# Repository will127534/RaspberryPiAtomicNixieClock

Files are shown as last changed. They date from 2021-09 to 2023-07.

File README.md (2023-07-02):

# RaspberryPi Atomic Nixie Clock

[Full description is in here](https://www.willwhang.dev/RaspberryPi-Atomic-Nixie-Clock/)



## Sys Arch


## Source File List
* PCB - PCB related board designed with KiCad v5.99 nightly
* FPGA Code - Verilog files
* Raspberry Pi Code - Python + C code to interact with FPGA

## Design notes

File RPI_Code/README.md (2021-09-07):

# Raspberry Pi Code

The code is intended to document the communication with the FPGA and SA.3xm Atomic Clock.

## Setup

### Python Library
```
pip install -r requirements.txt
```
Library List:
* influxdb Client
* pyserial
* simple_pid
* adafruit-circuitpython-TMP117
* python-dateutil

### GPS
gpsd is not actually needed but I'm using it to parse some GPS NEMA data and connect to ntpd, so the program is designed around gpsd and take its serial dump and parse the UBX format phase error data.

Note also you should enable UBX-TIM-TP output of the uBlox GPS module.

### InfluxDB
InfluxDB is used to collect time series data. The setting is in **dbSetting.py**

## Code List

* **uploadClock.py**
    * The main program to communicate with FPGA
    * Reading FPGA data, including TDC7200 measurement
    * Setting up FPGA time and inital PPS alignment
    * Reading GPS Serial data from stdin and calculate corrected PPS error
    * Nixie Tube animate to prevent cathode poisoning
* **uploadMAC.py**
    * Reading MAC status and creating UDP server for other program to communicate with MAC. (**calibrateClock.py**)
* **calibrateClock.py**
    * The program to read current PPS error using InfluxDB and tune the clock EFC. The EFC tuning cmd is send via UDP package to **uploadMAC.py**. The tuning algroithm is a simple accumlated error.
* **readADC**
    * The C program to poll ADC reading and output frequency and Vrms data to stdio.
    * `gcc -o readADC ./readADC.c -lm -mcpu='cortex-a72' -O3`
    * `./readADC [folderPath]`
* **autoBrightness**
    * The C program to control Nixie Tube brightness. Reading Lux sensor and send cmd to FPGA.
    * `g++ -o autoBrightness ./main.cpp ./Adafruit_PWMServoDriver.cpp ./TSL2561.cpp -lwiringPi`
    * `autoBrightness [lowest_pwm]`
* **fanControl.py**
    * Reading TMP117 and using PID loop on the bottom fan to maintain the clock temperature
* mountdrive.sh
    * Creating a 512MB ramdisk to store AC waveform, and mounting NVMe drive.
* **moveFile.py**
    * Copy the file from ramdisk to NVMe drive.
* **uploadFPGA.py**
    * Uploading FPGA bin file via SPI
* **uploadFPGA.sh**
    * The helper shell script of **uploadFPGA.py**
* **dbSetting.py**
    * The settings for InfluxDB location

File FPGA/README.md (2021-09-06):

# Verilog Files

Designed for iCE5LP

## File List
 * **main.v** - top verilog code
 * Driver
     * **ADS8681.v** - ADS8681 Driver
     * **tdc7200.v** - TDC7200 Driver
     * **nixie.v** - HV5623/HV5623 Driver
     * **spi_master.v** - SoftIP SPI, used by the Drivers
     * **spi_slave.v** - Using HardIP block
 * Utility
     * **coarsecounter.v** - Simple Counter
     * **bin2bcd.v** - Binary to BCD Code for Nixie Tube
     * **delayPPS.v** - Generate constant cycle delay for a given input signal
     * **fifo.v** - FIFO using BRAM blocks
     * **pps.v** - Generate PPS signal, and optionaly can align with external PPS
     * **pwm.v** - Actually it is generating PDM signal
     * **rtc.v** - A really simple RTC, just counting the time for Nixie Clock
 * Testbench
     * **counter_test.v** - coarsecounter.v testing
     * **pdm_test.v** - pwm.v testing
     * **spi_m_test.v**
     * **spi_s_test.v**
 * **pins.pcf** - pin definition

## iCECube2 output 
> Device Utilization Summary
    LogicCells                  :	2050/3520
    PLBs                        :	346/440
    BRAMs                       :	16/20
    IOs and GBIOs               :	31/35
    PLLs                        :	0/1
    I2Cs                        :	0/2
    SPIs                        :	2/2
    DSPs                        :	0/4
    SBIOODs                     :	3/4
    LEDDRVs                     :	0/1
    RGBDRVs                     :	0/1
    IRDRVs                      :	0/1
    LEDDIPs                     :	0/1
    LFOSCs                      :	0/1
    HFOSCs                      :	1/1

>Number of clocks: 5
Clock: main|CLOCK | Frequency: 65.57 MHz | Target: 15.00 MHz
Clock: main|SCK | Frequency: 394.30 MHz | Target: 15.00 MHz
Clock: osc2.hfosc/CLKHF | Frequency: 113.89 MHz | Target: 48.00 MHz
Clock: rpi_adc_dev.sb_spi_inst/SCKO | Frequency: N/A | Target: 25.00 MHz
Clock: rpi_spi_dev.sb_spi_inst/SCKO | Frequency: N/A | Target: 25.00 MHz

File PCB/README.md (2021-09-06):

# PCB Files
Designed with KiCad v5.99 nightly build

## PCB Errata
1. EMC2301 package is wrong
2. eFUSE (TPS259270) Enable pin should connect to VIN via a resistor 

## Images



good luck finding the stock for LDO and DC-DC converters :D

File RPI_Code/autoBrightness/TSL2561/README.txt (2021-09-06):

**DEPRECATED**
Please use new version of library:
https://github.com/adafruit/Adafruit_TSL2561

---------------------------
This is an Arduino library for the TSL2561 digital luminosity (light) sensors. 

Pick one up at http://www.adafruit.com/products/439

To download. click the DOWNLOADS button in the top right corner, rename the uncompressed folder TSL2561. Check that the TSL2561 folder contains TSL2561.cpp and TSL2561.h

Place the TSL2561 library folder your <arduinosketchfolder>/libraries/ folder. You may need to create the libraries subfolder if its your first library. Restart the IDE.

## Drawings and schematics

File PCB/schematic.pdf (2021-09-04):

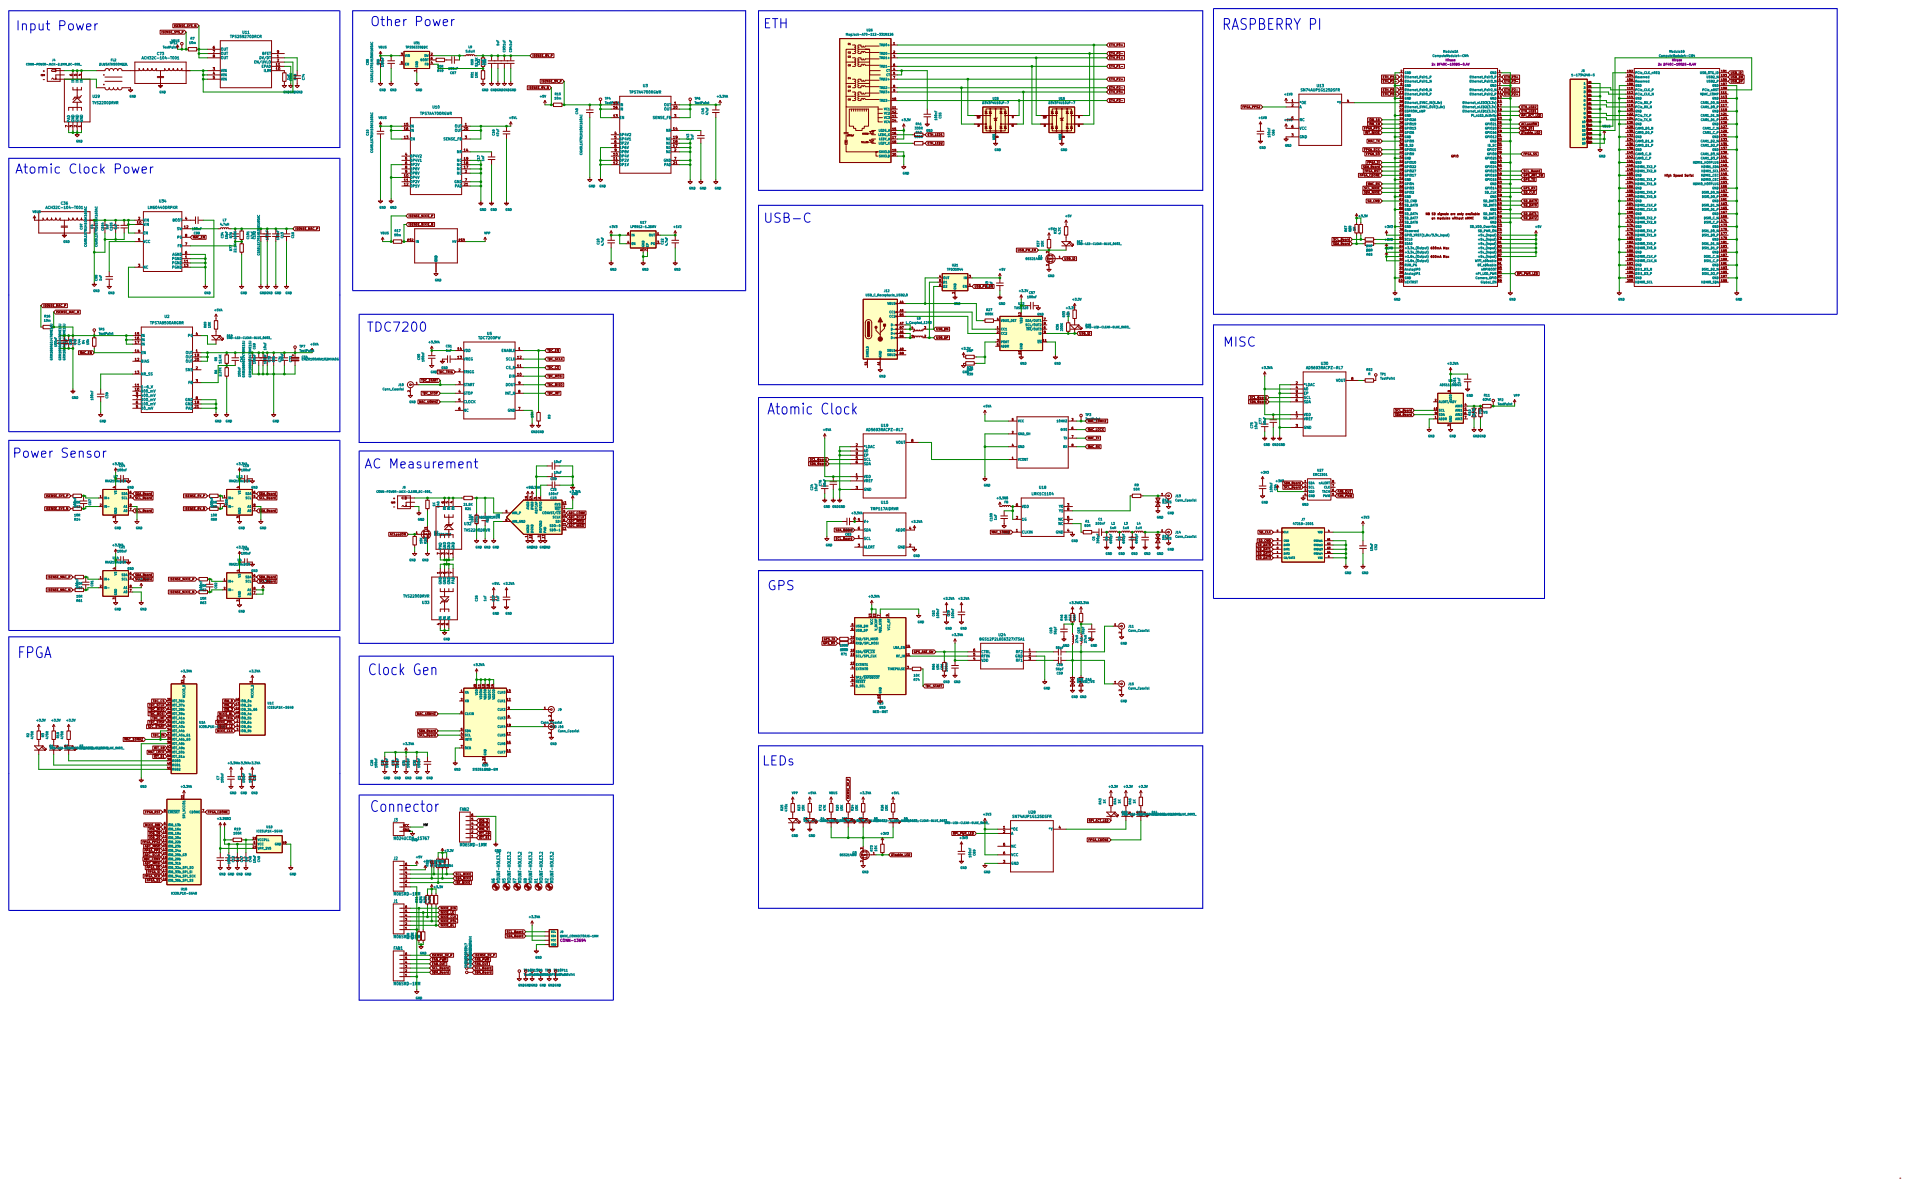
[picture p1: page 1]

1 SW 2 VIN 3 FB 4 EN 5 BOOT 6 U31 TPS56339DDC

D14SMD-LED-CLEAR-BLUE_0603_ D10SMD-LED-CLEAR-BLUE_0603_ GND

600mA Max 600mA Max NB SD signals are only available

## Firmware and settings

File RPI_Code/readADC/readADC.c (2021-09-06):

#define _GNU_SOURCE
#include <stdint.h>
#include <unistd.h>
#include <stdio.h>
#include <stdlib.h>
#include <getopt.h>
#include <fcntl.h>
#include <sys/ioctl.h>
#include <linux/types.h>
#include <linux/spi/spidev.h>
#include <string.h>
#include <stdbool.h>
#include <time.h>
#include <fcntl.h>
#include <sys/time.h>
#include <inttypes.h>
#include <math.h>
#include <sched.h>
#include <sys/mman.h>
#include <sys/types.h>
#include <sys/wait.h>
#include <sys/types.h>
#include <sys/ipc.h>
#include <sys/shm.h>

// File Related Var
char *folder;
FILE *ADCFile;
FILE *FreqFile;
bool changed_FreqFile,changed_ADCFile;

// Calculate Freq, Vrms, Max, Low Voltage Related Var
bool positive_flag = 0;
uint16_t last_timestamp = 0;
double last_timestamp_fp = 0;
double last_adc_voltage = 0;
double heighest_voltage = 0;
double lowset_voltage = 0;
double rms_voltage_square_sum = 0;
int rms_voltage_count = 0;

// FPGA data Related Var
uint16_t *read_count;
uint32_t *secondsOfDay;
uint16_t *pps_timestamp;
char *buf_data;

//FIFO Related Var
volatile uint16_t *queue_write;
volatile uint16_t *queue_read;
const uint16_t queue_length = 3000;

//Read FIFO FPGA CMD
const char buf_readFIFO[9] = {128+2,0x00,0x00,0x00,0x00,0x00,0x00,0x00,0x00};

//Init SPIdev
int spi_init(char filename[40]){
    int file;

    if ((file = open(filename,O_RDWR)) < 0)
    {
        printf("Failed to open the bus.");
        /* ERROR HANDLING; you can check errno to see what went wrong */
        exit(1);
    }
    return file;
}

//Clear FPGA FIFO
void setup_fifo(int file, struct spi_ioc_transfer xfer_conf){
    int status;
    char buf[2] = {0x00,0x04};
    //xfer.tx_buf = (unsigned long) buf_out;
    //xfer.len = 4; /* Length of  command to write*/
    xfer_conf.rx_buf = (unsigned long) NULL;
    xfer_conf.tx_buf = (unsigned long) buf;
    xfer_conf.len = 2; /* Length of Data to read */

    status = ioctl(file, SPI_IOC_MESSAGE(1), &xfer_conf);
    if (status < 0) {
        perror("SPI_IOC_MESSAGE");
        return ;
    }
}

//Write Frequency to File
void writeFrequency(uint16_t timestamp, double frequency, double rms_voltage){
    time_t current_time;
    struct tm * time_info;
    char buffer[200] = {0};

    time_t s;  // Seconds
    struct timespec spec;
    clock_gettime(CLOCK_REALTIME, &spec);
    s  = spec.tv_sec;
    sprintf(buffer, "%"PRIdMAX".%09ld,%d,%f,%f\n",(intmax_t)s, spec.tv_nsec,timestamp,frequency,rms_voltage);

    fwrite(buffer,1,strlen(buffer),FreqFile);
    time(&current_time);
    time_info = localtime(&current_time);
    if ((time_info->tm_min % 5 == 0) & (changed_FreqFile == 0)) //Switch file per 5 min
    {
        char timeString[100] = {0};
        char fileString[100] = {0};
        strftime(timeString, sizeof(timeString), "ACFREQ_%Y%m%d_%H%M%S.txt", time_info);
        sprintf(fileString,"%s%s",folder,timeString);

        fclose(FreqFile);
        FreqFile = fopen(fileString,"w" );
        changed_FreqFile = 1;
    }
    if ((time_info->tm_min % 5 == 1) & (changed_FreqFile == 1))
    {
        changed_FreqFile = 0;
    }
}

//Process ADC raw data from FPGA
void process_data(int length, uint8_t* buf_in){
    for (int k=0;k<length;k++){
        for (int i=0;i<4;i++){
                uint16_t timestamp = (uint16_t)buf_in[1+k*16+i*4]*256+(uint16_t)buf_in[0+k*16+i*4];
                uint16_t adc_data = (uint16_t)buf_in[3+k*16+i*4]*256+(uint16_t)buf_in[2+k*16+i*4];
                int fifo = 0;
                if(k==0 & i == 0)
                    fifo = *read_count;
                double voltage = ((double)adc_data - 32813.7864224796) * 0.001032546059765 -0.013938492775101;
                if(voltage > heighest_voltage) heighest_voltage = voltage;
                if(voltage < lowset_voltage) lowset_voltage = voltage;
                char buffer[200] = {0};
                //ASCII Format
                //sprintf(buffer, "%d,%d,%d,%d,%f\n",*secondsOfDay,fifo,timestamp,adc_data,voltage);
                //printf("%s",buffer);
                //fwrite(buffer,1,strlen(buffer),ADCFile);

                //Binary File Format 
                memcpy(buffer,secondsOfDay,sizeof(uint32_t));
                memcpy(buffer+4,read_count,sizeof(uint32_t));
                memcpy(buffer+8,&timestamp,sizeof(uint16_t));
                memcpy(buffer+10,&adc_data,sizeof(uint16_t));
                fwrite(buffer,1,12,ADCFile);

                if ( voltage>0 && positive_flag == 0 ){ //Zero corssing from negitive to positive
                    double current_timestamp_fp = -1 * last_adc_voltage / (voltage - last_adc_voltage);
                    uint16_t timestamp_duration = 0;
                    if(timestamp<last_timestamp) timestamp_duration = 50000-last_timestamp+timestamp;
                    else timestamp_duration = timestamp - last_timestamp;
                    double cycle_time = (double)timestamp_duration * 1 / 50000 + (current_timestamp_fp - last_timestamp_fp)* 1 / 50000;
                    double frequency = 1/cycle_time;
                    double rms_voltage = sqrt(rms_voltage_square_sum/rms_voltage_count);
                    printf("%f,%f,%5d.%0.5f,%5d.%0.5f,%f,%f,%f,%f,%f\n",last_adc_voltage,voltage,timestamp,current_timestamp_fp,last_timestamp,last_timestamp_fp,cycle_time,frequency,rms_voltage,heighest_voltage,lowset_voltage);
                    writeFrequency(timestamp,frequency,rms_voltage);
                    last_timestamp = timestamp;
                    last_timestamp_fp = current_timestamp_fp;
                    lowset_voltage = 0;
                    heighest_voltage = 0;
                    rms_voltage_square_sum = 0;
                    rms_voltage_count = 0;
                }

                rms_voltage_square_sum += voltage*voltage;
                rms_voltage_count += 1;

                positive_flag = (voltage>0);
                last_adc_voltage = voltage;
        }
    }
}


void main(int argc, char *argv[]){
    folder = argv[1];

    // Share Memory for Thread communication 
    int shm_id;
    shm_id = shmget(IPC_PRIVATE, 12+3000*16, IPC_CREAT | 0666);
    if (shm_id < 0) {
         printf("shmget error\n");
         exit(1);
    }

    // Forking two thread - Reading and Processing
    pid_t child_a, child_b;
    child_a = fork();

    if (child_a == 0) {
        /* Child code */
        printf("Read Thread Start\n");

        //Get the share memory
        char *shm_addr;
        shm_addr = shmat(shm_id, NULL, 0);
        if (shm_addr == (char *)(-1)) {
            perror("shmat");
            exit(1);
        }

        //Start of the SHM is the pointer of FIFO and FPGA data
        queue_write = (uint16_t*)shm_addr;
        queue_read = (uint16_t*)shm_addr + 2;

        read_count = (uint16_t*)shm_addr + 4;
        secondsOfDay = (uint32_t*)shm_addr + 6;
        pps_timestamp = (uint16_t*)shm_addr + 10;

        //FIFO Data is after this
        buf_data = (char*)shm_addr + 64;

        //Set write point to 0
        *queue_write = 0;

        //Lock the reading thread to CPU 2 only
        cpu_set_t  mask;
        CPU_ZERO(&mask);
        CPU_SET(2, &mask);
        int result = sched_setaffinity(0, sizeof(mask), &mask);


        //INIT SPI
        char buf_in_DATA[255*16+2];
        char buf_in_FIFO[9] = {0};
        int file=spi_init("/dev/spidev0.1");
        int file_conf=spi_init("/dev/spidev0.0"); 

        int mode = SPI_MODE_0;
        ioctl(file,SPI_IOC_WR_MODE,&mode);

        struct spi_ioc_transfer xfer[2];
        struct spi_ioc_transfer xfer_conf;
        memset((void*)&xfer_conf,0,sizeof(xfer_conf));
        memset((void*)xfer,0,sizeof(xfer));

        xfer[0].len = 4; 
        xfer[0].cs_change = 0; 
        xfer[0].delay_usecs = 0,
        xfer[0].speed_hz = 12500000, 
        xfer[0].bits_per_word = 8, 

        xfer[1].len = 4; 
        xfer[1].cs_change = 0; 
        xfer[1].delay_usecs = 0, 
        xfer[1].speed_hz = 12500000,
        xfer[1].bits_per_word = 8, 

        xfer_conf.len = 4; 
        xfer_conf.cs_change = 0; 
        xfer_conf.delay_usecs = 0, 
        xfer_conf.speed_hz = 6250000, 
        xfer_conf.bits_per_word = 8, 

        //CLEAR FIFO
        setup_fifo(file_conf,xfer_conf);

        while(1){
            //Read FIFO count, ADC_Tag, Current Time
            xfer_conf.rx_buf = (unsigned long) buf_in_FIFO;
            xfer_conf.tx_buf = (unsigned long) buf_readFIFO;
            xfer_conf.len = 9;

            int status = ioctl(file_conf, SPI_IOC_MESSAGE(1), &xfer_conf);
            if (status < 0)
                {
                perror("SPI_IOC_MESSAGE");
                return;
                }
            //printf("env: %02x %02x %02x %02x %02x\n", buf_out[0], buf_out[1], buf_out[2], buf_out[3],buf_out[4]);
            //printf("ret: %02x %02x %02x %02x %02x %02x %02x %02x %02x\n", buf_in_2[0], buf_in_2[1], buf_in_2[2], buf_in_2[3], buf_in_2[4], buf_in_2[5], buf_in_2[6], buf_in_2[7], buf_in_2[8]);

            *read_count = buf_in_FIFO[3]*256+buf_in_FIFO[2];
            *secondsOfDay = (int)buf_in_FIFO[8]*3600+(int)buf_in_FIFO[7]*60+(int)buf_in_FIFO[6];
            *pps_timestamp = buf_in_FIFO[5]*256+buf_in_FIFO[4];

            //printf("Reading....%d,%d,%d\n",*read_count,*pps_timestamp,*secondsOfDay);

            //If FIFO count is not zero then read the indicated amount
            if (*read_count == 0) continue;
            int transferCount = *read_count > 255 ? 255 : *read_count;

            xfer[0].rx_buf = (unsigned long) buf_in_DATA;
            xfer[0].tx_buf = (unsigned long) NULL;
            xfer[0].len = transferCount*16 + 2; 

            //printf("Reading....%d\n",transferCount);
            status = ioctl(file, SPI_IOC_MESSAGE(1), &xfer);
            if (status < 0){
                perror("SPI_IOC_MESSAGE");
                return;
            }

            //Put to SHM and advance write pointer
            memcpy(buf_data+*queue_write*16,buf_in_DATA+2,transferCount*16);
            int queue_write_next = (*queue_write+transferCount)%queue_length;
            //*queue_write += transferCount;
            *queue_write = queue_write_next;

            //Clear SPI buffer
            memset(buf_in_DATA,0,sizeof(buf_in_DATA));
        }
    } 
    else {
        printf("Process Thread Start\n");

        //Open file with timestamp
        time_t current_time;
        struct tm * time_info;
        time(&current_time);
        time_info = localtime(&current_time);

        char timeString[100] = {0};
        strftime(timeString, sizeof(timeString), "Waveform_%Y%m%d_%H%M%S.bin", time_info);
        char fileString[100] = {0};
        sprintf(fileString,"%s%s",folder,timeString);
        printf("Write to: %s\n",fileString);
        ADCFile = fopen( fileString,"w");
        //fcntl(ADCFile, F_SETFL, O_NONBLOCK);

        strftime(timeString, sizeof(timeString), "ACFREQ_%Y%m%d_%H%M%S.txt", time_info);
        sprintf(fileString,"%s%s",folder,timeString);
        printf("Write to: %s\n",fileString);
        FreqFile = fopen(fileString,"w");

        int current_fileSecond = 0;

        //Open SHM
        char *shm_addr;
        shm_addr = shmat(shm_id, NULL, 0);
        if (shm_addr == (char *)(-1)) {
            perror("shmat");
            exit(1);
        }

        queue_write = (uint16_t*)shm_addr;
        queue_read = (uint16_t*)shm_addr + 2;

        read_count = (uint16_t*)shm_addr + 4;
        secondsOfDay = (uint32_t*)shm_addr + 6;
        pps_timestamp = (uint16_t*)shm_addr + 10;

        buf_data = shm_addr + 64;

        //Setup read pointer
        *queue_read = 0;

        while(1){
            if(*queue_read == *queue_write){
                //printf("Processing....%d,%d\n",*queue_read,*queue_write);
                usleep(1000*20);
                continue;
            }
            int queue_write_backup = *queue_write;
            //printf("Processing....%d,%d\n",*queue_read,queue_write_backup);
            if(*queue_read > queue_write_backup){
                int read_size = queue_length - *queue_read;
                process_data(read_size, buf_data+*queue_read*16);
                read_size = queue_write_backup;
                process_data(read_size, buf_data);
            }
            else{
                int read_size = queue_write_backup - *queue_read;
                process_data(read_size, buf_data+*queue_read*16);
            }
            *queue_read = queue_write_backup;

            if(*secondsOfDay % 60 == 0 && current_fileSecond != *secondsOfDay){
                fclose(ADCFile);
                time_t current_time;
                struct tm * time_info;
                time(&current_time);
                time_info = localtime(&current_time);

                int hour = *secondsOfDay/3600;
                int minute = (*secondsOfDay/60)%60;
                int seconds = *secondsOfDay%60;

                char dateString[100] = {0};
                strftime(dateString, sizeof(dateString), "Waveform_%Y%m%d_", time_info);
                char timeString[100] = {0};
                sprintf(timeString,"%02d%02d%02d.bin",hour,minute,seconds);
                char fileString[100] = {0};
                sprintf(fileString,"%s%s%s",folder,dateString,timeString);
                printf("Write to: %s\n",fileString);
                ADCFile = fopen(fileString,"w");
                current_fileSecond = *secondsOfDay;
            }
        }
    }
}

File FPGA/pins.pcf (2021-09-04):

# ##############################################################################

# iCEcube PCF

# Version:            2017.08.27940

# File Generated:     Mar 31 2019 12:09:07

# Family & Device:    iCE5LP4K

# Package:            SG48

# ##############################################################################

###IOSet List 21
set_io FPGA_PPS 23
set_io pin_led16 46
set_io AC_IN 20
set_io TCXO_IN 35
set_io EXT_IN 38
set_io MI 14
set_io NIXIE_CLK 11
set_io pin_ledG 40
set_io CS 27
set_io NIXIE_DIN 13
set_io NIXIE_LE 12
set_io PWM_FAN 6 -pullup yes
set_io PWM_FAN_INPUT 48 -pullup yes
set_io pin_led15 47
set_io pin_ledB 39
set_io pin_ledR 41
set_io vclk 44
set_io GPS_PPS 32
set_io MO 17
set_io NIXIE_BL 9
set_io NIXIE_POL 10
set_io SCLK 15
set_io FPGA_Counter_INT 21
set_io GPS_TX 34
set_io UART_DATA_INT 28
set_io CS_uart 18
set_io MAC_TX 36
set_io MAC_RX 37

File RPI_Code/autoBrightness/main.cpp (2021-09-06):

#include <iostream>
#include <errno.h>
#include <wiringPiI2C.h>
#include "TSL2561.h"
#include "Adafruit_PWMServoDriver.h"
#include <unistd.h>
#include <stdlib.h> 
#include <fcntl.h>
#include <sys/ioctl.h>
#include <linux/types.h>
#include <linux/spi/spidev.h>
#include <stdio.h>
#include <cstring>
#include <math.h>
using namespace std;

TSL2561 tsl; 
Adafruit_PWMServoDriver pwm = Adafruit_PWMServoDriver(0x60);
struct spi_ioc_transfer xfer[2];

int spi_init(char filename[40]){
    int file;

    if ((file = open(filename,O_RDWR)) < 0)
    {
        printf("Failed to open the bus.");
        /* ERROR HANDLING; you can check errno to see what went wrong */
        exit(1);
    }
    return file;
}

void write_PDM_Clock_Divider(int file, uint16_t div){
    int status;
    char buf1[2] = {12,div};
    char buf2[2] = {13,div>>8};
    //xfer.tx_buf = (unsigned long) buf_out;
    //xfer.len = 4; /* Length of  command to write*/
    xfer[0].rx_buf = (unsigned long) NULL;
    xfer[0].tx_buf = (unsigned long) buf1;
    xfer[0].len = 2; /* Length of Data to read */
    xfer[0].cs_change = 1; 
    xfer[1].rx_buf = (unsigned long) NULL;
    xfer[1].tx_buf = (unsigned long) buf2;
    xfer[1].len = 2; /* Length of Data to read */
    
    status = ioctl(file, SPI_IOC_MESSAGE(2), &xfer);
    if (status < 0) {
        perror("SPI_IOC_MESSAGE");
        return ;
    }
}

void write_PDM_value(int file, uint16_t val){
    int status;
    char buf1[2] = {10,val};
    char buf2[2] = {11,val>>8};

    //printf("sent: %02x %02x %02x %02x\n", buf1[0], buf1[1], buf2[0], buf2[1]);
    //xfer.tx_buf = (unsigned long) buf_out;
    //xfer.len = 4; /* Length of  command to write*/
    xfer[0].rx_buf = (unsigned long) NULL;
    xfer[0].tx_buf = (unsigned long) buf1;
    xfer[0].len = 2; /* Length of Data to read */
    xfer[0].cs_change = 1; 
    xfer[1].rx_buf = (unsigned long) NULL;
    xfer[1].tx_buf = (unsigned long) buf2;
    xfer[1].len = 2; /* Length of Data to read */

    
    status = ioctl(file, SPI_IOC_MESSAGE(2), &xfer);
    if (status < 0) {
        perror("SPI_IOC_MESSAGE");
        return ;
    }

}


void enable_PDM(int file){
    int status;
    char buf[2] = {0x00,0x10};
    //xfer.tx_buf = (unsigned long) buf_out;
    //xfer.len = 4; /* Length of  command to write*/
    xfer[0].rx_buf = (unsigned long) NULL;
    xfer[0].tx_buf = (unsigned long) buf;
    xfer[0].len = 2; /* Length of Data to read */

    status = ioctl(file, SPI_IOC_MESSAGE(1), &xfer);
    if (status < 0) {
        perror("SPI_IOC_MESSAGE");
        return ;
    }
}

int main(int argc, char **argv)
{
  if (argc < 2){
    cout << "./main [lowest_pwm]" << "\n"; 
  }
  int input = atoi(argv[1]);
  if(input > 4095) input = 4095;
  if(input < 0) input = 0;
  uint16_t lowest_PWM = input;

  int fd = wiringPiI2CSetup(TSL2561_ADDR_LOW);
  cout << "Init result: "<< fd << endl;

  if (tsl.begin(fd)) {
    cout << "Found sensor"<< fd << endl;
  } else {
    cout << "No sensor"<< fd << endl;
    while (1);
  }

  tsl.setGain(TSL2561_GAIN_16X);
  tsl.setTiming(TSL2561_INTEGRATIONTIME_101MS);


  memset((void*)xfer,0,sizeof(xfer));
  xfer[1].cs_change = 0;
  xfer[1].delay_usecs = 0;
  xfer[1].speed_hz = 6250000;
  xfer[1].bits_per_word = 8;
  xfer[0].cs_change = 0; 
  xfer[0].delay_usecs = 0;
  xfer[0].speed_hz = 6250000;
  xfer[0].bits_per_word = 8;

  int file_conf=spi_init("/dev/spidev0.0"); 
  enable_PDM(file_conf);
  write_PDM_Clock_Divider(file_conf,3000);

  pwm.begin();
  pwm.setPWMFreq(1000);
  for(int i=12;i<16;i++)
    pwm.setPWM(i, 0, 0);
  for (uint8_t pwmnum=4; pwmnum < 12; pwmnum++) {
    pwm.setPWM(pwmnum, 0, 4095);
  }

   while(1)
   {
      uint32_t lum = tsl.getFullLuminosity();
      uint16_t ir, full;
      ir = lum >> 16;
      full = lum & 0xFFFF;
      uint32_t lux = tsl.calculateLux(full, ir);
      

      uint16_t dutyCycle = pow(1.009, lux)*720.161525918474+2000;
      if (dutyCycle>65535){
        dutyCycle = 65535;
      }
      cout << "Lux:" << lux <<endl;
      //cout << "dutyCycle:" << dutyCycle <<endl;
      write_PDM_value(file_conf,dutyCycle);

      /*
      for (uint8_t pwmnum=4; pwmnum < 12; pwmnum++) {
        pwm.setPWM(pwmnum, 0, dutyCycle);
      }
      */
      //result = wiringPiI2CWriteReg16(fd, 0x40, (i & 0xfff) );
      /*
      if(result == -1)
      {
         cout << "Error.  Errno is: " << errno << endl;
      }
      */
   }
}
